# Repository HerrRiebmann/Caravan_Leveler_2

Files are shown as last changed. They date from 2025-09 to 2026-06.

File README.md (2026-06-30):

# Caravan Leveler 2.0
ESP32 digital water level bubble with an MPU6050 Gyroscope & Accelerometer

The successor of the [Caravan Leveler 1.0](https://github.com/HerrRiebmann/Caravan_Leveler)

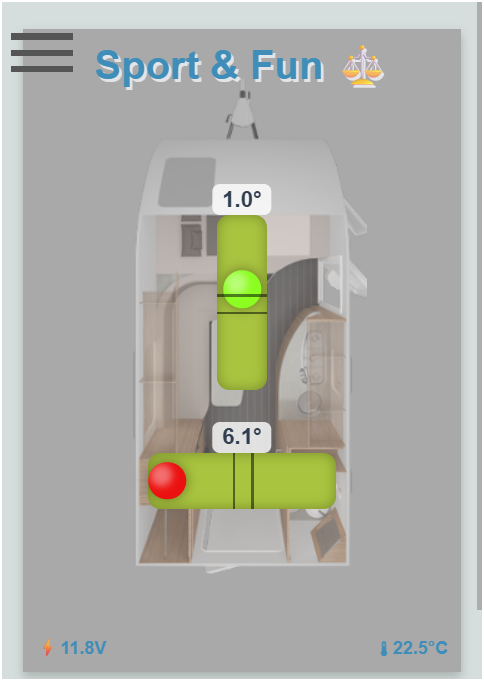
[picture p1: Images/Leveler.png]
Caravan Leveler


An ESP32 will create a hotspot with a captive portal.
This captive portal will force the phone to open up a, usually for login intended, website (_which represents the water level_).





## Contents
* [Usage](#usage)
* [Things](#Things)
* [Installation](#Installation)
* [HardwareComponents](#HardwareComponents)
  * [Wiring](#Wiring)
  * [SPIFFS Upload](#SPIFFS-Upload)
  * [Libraries](#Libraries)
  * [OTA (Over the Air Update)](#OTA-Over-the-Air-Update)
* [Compatibility](#Compatibility)
* [Demo](#Demo)
* [Video](#Video)

### Intention
The intention was, to attach this to my caravan (_Knaus Sport & Fun_) and provide it with 12V on-board voltage.
When arriving at a campingside, the phone will automatically connect to this as a known hotspot, open up the digital leveler and I can happily crank the supports.

In short: Lazy me doesn´t want to constantly walk to the inside and check the level &#129335;

## Usage

### Main Menu

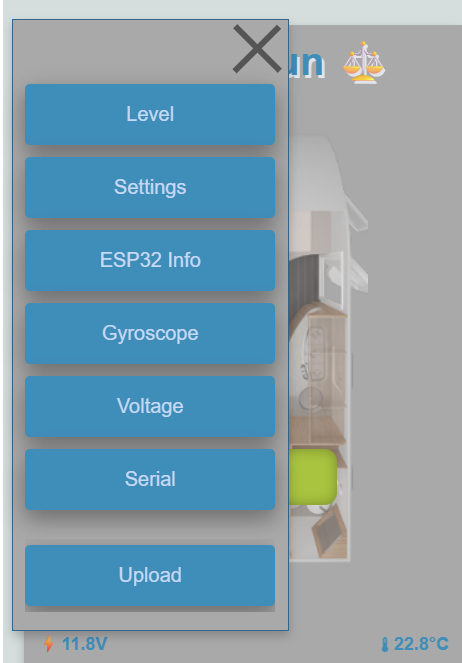
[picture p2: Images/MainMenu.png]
Main Menu


 * **Upload** loads a file to the SPIFFS filesystem. To overwrite existing files, the filename must be equal (see [/data](https://github.com/HerrRiebmann/Caravan_Leveler_2/tree/main/Caravan_Leveler_2/data))! The filenames are case sensitive!

  * Or updates the firmware by uploading a *.bin file.
  * Or updates the spiffs with a spiffs.*.bin file. See [Manual SPIFFS Upload](#Manual-SPIFFS-Upload)

### Settings

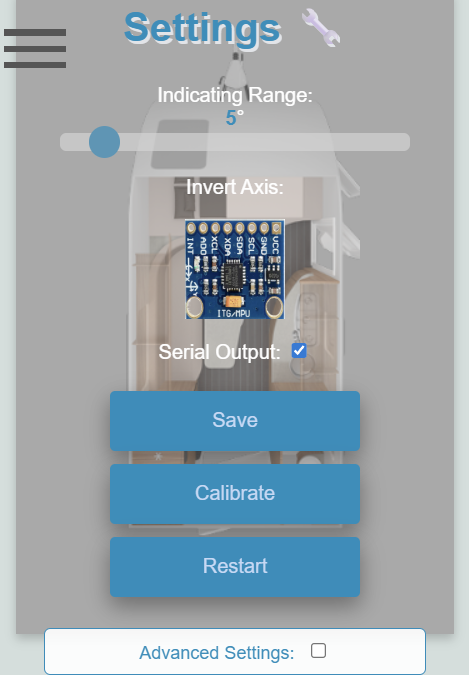
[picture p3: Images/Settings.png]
Settings


 * **Indicating Range** describes the water bubble maximum value, when it will reach the scales end

 * **Invert Axis** turns the MPU6050 Gyro (_swaps X- and Y-Axis_)

 * **Serial Output** enables USB serial (_and webbased_) output 

 * **Save** will store all values to the ESP32

 * **Calibrate** sets the current degrees to zero (ensure the Gyro is leveled)

 * **Restart** reboots the ESP32

 * **Advanced Settings** opens further settings

Advanced Settings:

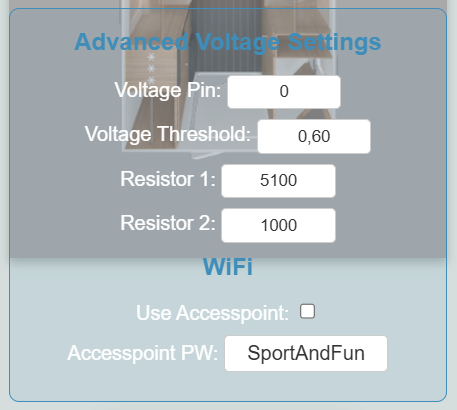
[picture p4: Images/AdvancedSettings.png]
Advanced Settings

#### Advanced Voltage Settings

 * **Voltage Pin** Analog ADC pin number for voltage measurement (0-36) *Check your ESP for ADC inputs!*

 * **Voltage Threshold** threshold to correct differences by diodes and resistors

 * **Resistor 1** First resistor value in ohms for voltage divider (After 12V, Before measuring)

 * **Resistor 2** Second resistor value in ohms for voltage divider (After measuring, before GND)

#### WiFi

 * **Use Accesspoint** or connect to an existing WiFi (_SSID and Pasword required in code or can be set on the web-installer_)

 * **Accesspoint PW** Password to secure the Accesspoint access

#### MPU6050

 * **SDA Pin** I²C Serial Data GPIO

 * **SCL Pin** I²C Serial Clock Line GPIO
   
 * **I²C Adress** Integer representation for the I2C adress (104 or 105)

### Gimmicks

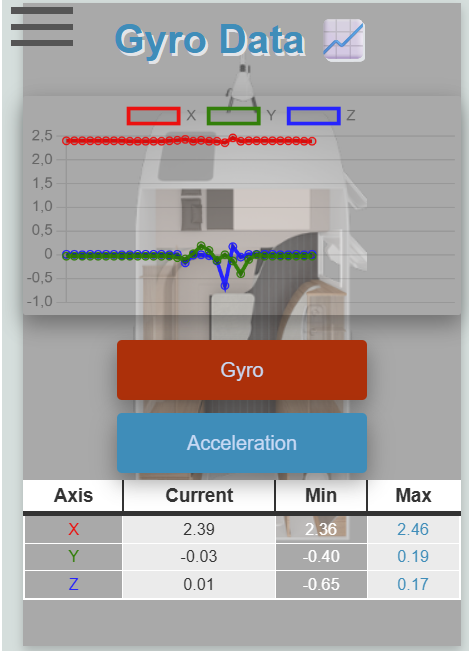
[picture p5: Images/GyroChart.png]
Gyro Chart


A Chart for Gyro, Acceleration and Voltage. Mostly just to debug and play around.

The Serial is also only implemented for testing purpose.

## Things
### Installation
You can download the files here, add the additional libraries and flash them via the Arduino IDE. All Libraries & Tools mentioned below.
Or you can use the ESP32 Web firmware flash-method, which will install all the required components directly onto the ESP.

Currently supported Versions are ESP32, ESP32-S3 & ESP32-C3.

[Caravan Leveler - Web Installer](https://trib.free.nf/flash.html?source=github)

This makes use of the [ESP Web Tools](https://esphome.github.io/esp-web-tools/) from ESPhome, hosted on unpkg.com.

### HardwareComponents
* ESP32 C3 Supermini (Any other ESP32 will work)
* MPU6050 (_Accelerometer / Gyro_)
* LM2596 (_DC-DC converter_)
* 5.2k & 1k Ohm Resistor (_For measuring voltage_)
* 2 Diodes to prevent voltage reversing (_like SR560 or SB5100_)

### Wiring
Wiring for my tested ESP32 types. Check the I2C pinout for your board!

 MPU6050 | ESP 32 | ESP32-S3 | ESP32-C3
 -------- |-------|-------|-------
 SCL | G22 | G09 | G09
 SDA | G21 | G08 | G08
 VCC | 3.3V | 3.3V | 3.3V
 GND | GND | GND | GND

The I²C adress will be 0x68 (Integer 104). In some cases, this might be 0x69 (105) when the jumper is set onto the board.

ESP 32 | LM2596
------- | --------
VIN 5V | OUT+
GND | OUT-

**Voltage Divider**
Any possible ADC Pin can be used. Please check it with the pinout for your device from the ESP32-family.

 Type | Pin
  ----- | -----
  ESP32 | 34
  ESP32-S3 | 1
  ESP32-C3 | 0

For most other ESP32 Development Boards pin 30-36.

```
-Supply voltage (max 15V!!!)
|----LM2596 IN+
|5.2k Resistor
|----Connect ADC-Pin
|1k Resistor
|----LM2596 IN-
-GND
```

### Schematic
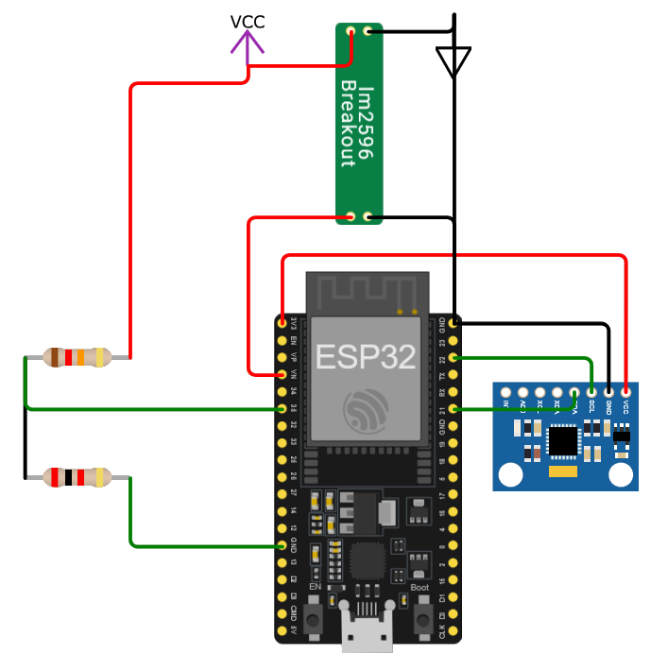
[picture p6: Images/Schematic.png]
Schematic


Diodes to secure the parts from reversed polarity were highly recommended!

### SPIFFS Upload
To upload the HTML, JS and CSS files, I´ve used the [Arduino ESP32 filesystem uploader](https://github.com/me-no-dev/arduino-esp32fs-plugin)
You can find the latest release [here](https://github.com/me-no-dev/arduino-esp32fs-plugin/releases/) and a tutorial on [RandomNerdTutorials](https://randomnerdtutorials.com/install-esp32-filesystem-uploader-arduino-ide/)

For **Arduino IDE 2.X** use the VSIX from [arduino-spiffs-upload](https://github.com/espx-cz/arduino-spiffs-upload) 

_This is only necessary if you want to compile the code yourself and upload the webinterface to the ESP32 afterwards._

#### Manual SPIFFS Upload
It is possible to use the Upload functionality on the Caravan Leveler to update the Website files all at once.
It automatically indentifies if this is a SPIFFS package an put it on the right spot on the storage.

The SPIFFS binary can be found here: [spiffs-binary](https://trib.free.nf/spiffs.bin) 

_Be aware, all your image customizations will be overwritten. The Settings will not be affected_

### Libraries
* Adafruit_MPU6050.h ([2.2.6](https://github.com/adafruit/Adafruit_MPU6050))
* Adafruit Unified Sensor ([1.1.15](https://github.com/adafruit/Adafruit_Sensor))
* Improv WiFi Library ([0.0.1](https://github.com/jnthas/Improv-WiFi-Library))

### OTA (Over the Air Update)
You should see the ESP32 in Arduino IDE under Tools -> Port -> Network-Interfaces (Caravan Leveler at _IP-Adress_)
For more information see [RandomNerdTutorials](https://randomnerdtutorials.com/esp32-over-the-air-ota-programming/)

## Compatibility
Installed on ESP32 C3 Supermini, ESP-WROOM-32 DevBoard and ESP32-S3-WROOM-1 DevBoard (with 2 USB-C)
Tested on Firefox, Chrome & Edge for Windows, iOS and Chrome & Firefox for Android.

## Demo
The website, which will be hosted on the ESP32 can be tested here:
[Caravan Leveler 2.0 - Demo](https://trib.free.nf/CaravanLevelerDemo/index.html?source=github)

## Video
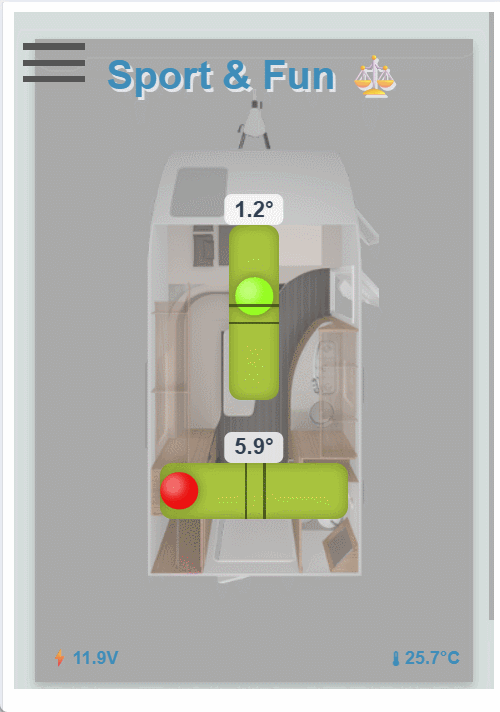
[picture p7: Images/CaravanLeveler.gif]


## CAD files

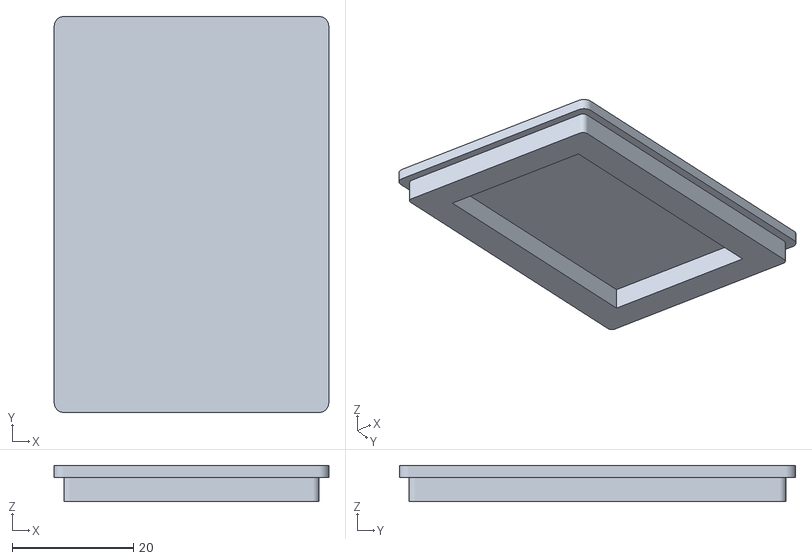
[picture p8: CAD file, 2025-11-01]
3D Case/ESP32 Supermini on Board/Caravan Leveler 2-Lid V3.stl
45.2 x 65.2 x 6.00

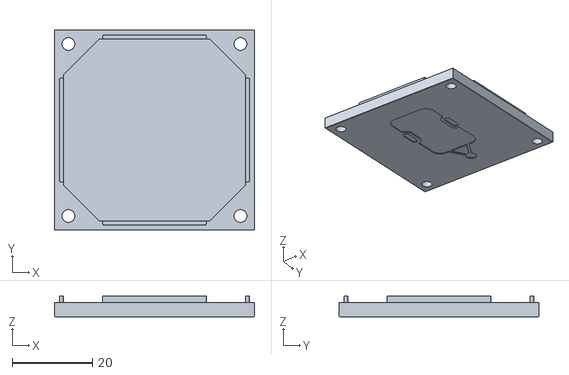
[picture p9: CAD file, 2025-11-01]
3D Case/ESP32/DeckelLeveler.stl
50.0 x 50.0 x 5.20

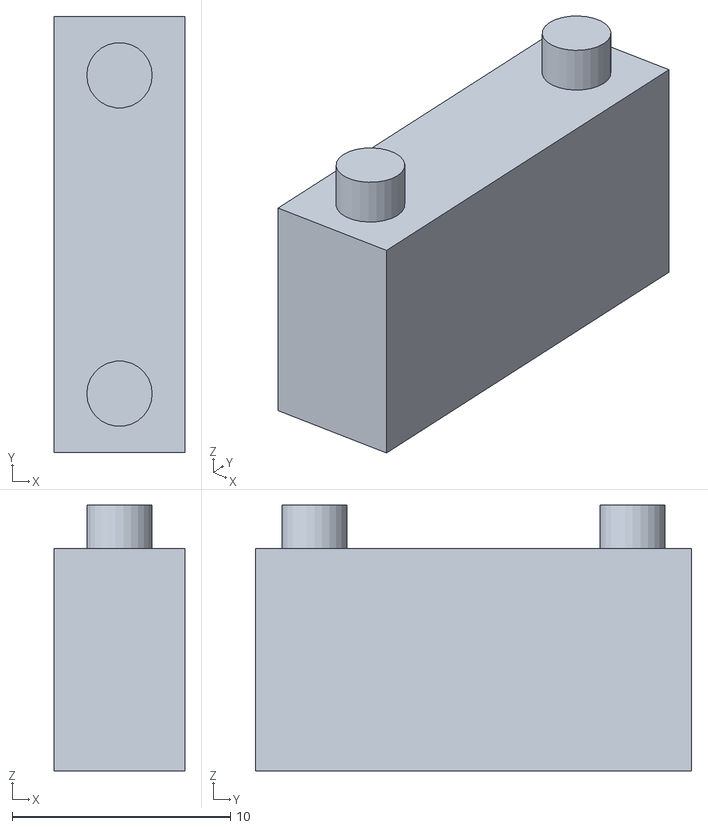
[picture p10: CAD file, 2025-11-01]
3D Case/ESP32 Supermini on Board/Caravan Leveler 2-GyroHolder.stl
6.00 x 20.0 x 12.2

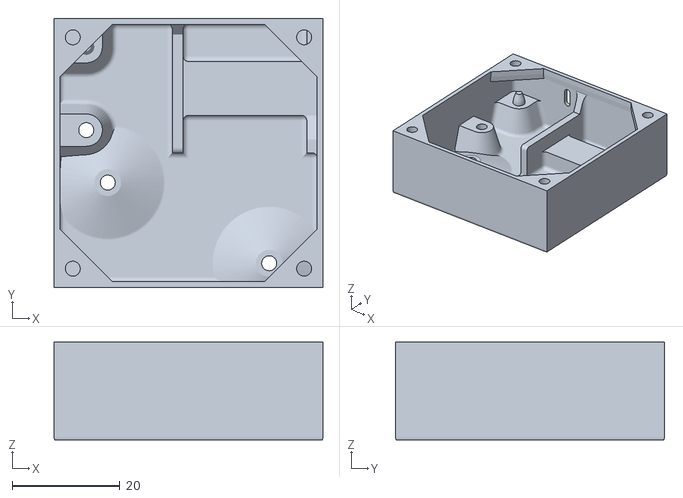
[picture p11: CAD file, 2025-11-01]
3D Case/ESP32/GehauseLeveler.stl
50.0 x 50.0 x 18.2

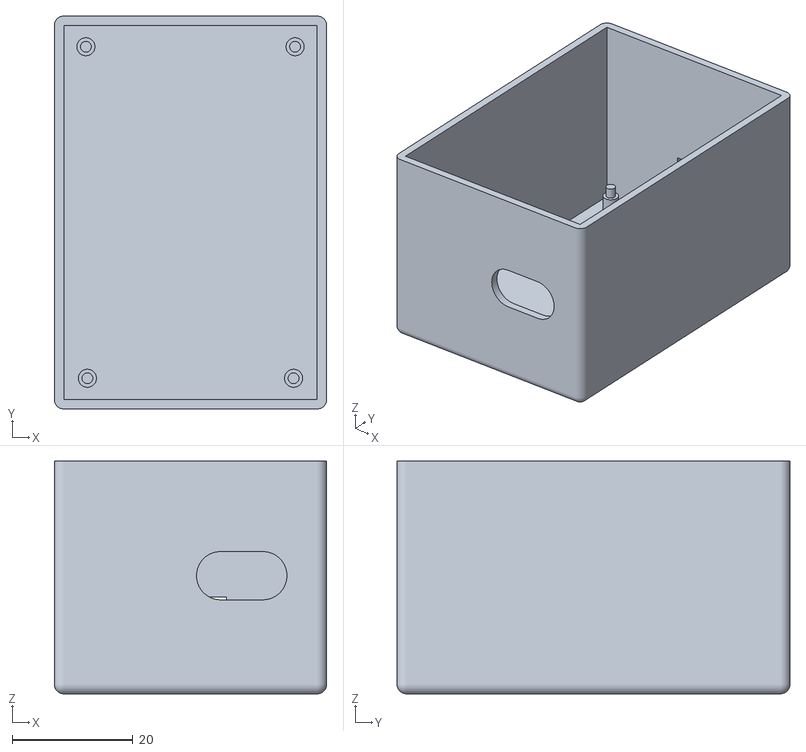
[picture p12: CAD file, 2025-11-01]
3D Case/ESP32 Supermini on Board/Caravan Leveler 2-Body V2.stl
45.2 x 65.2 x 38.6

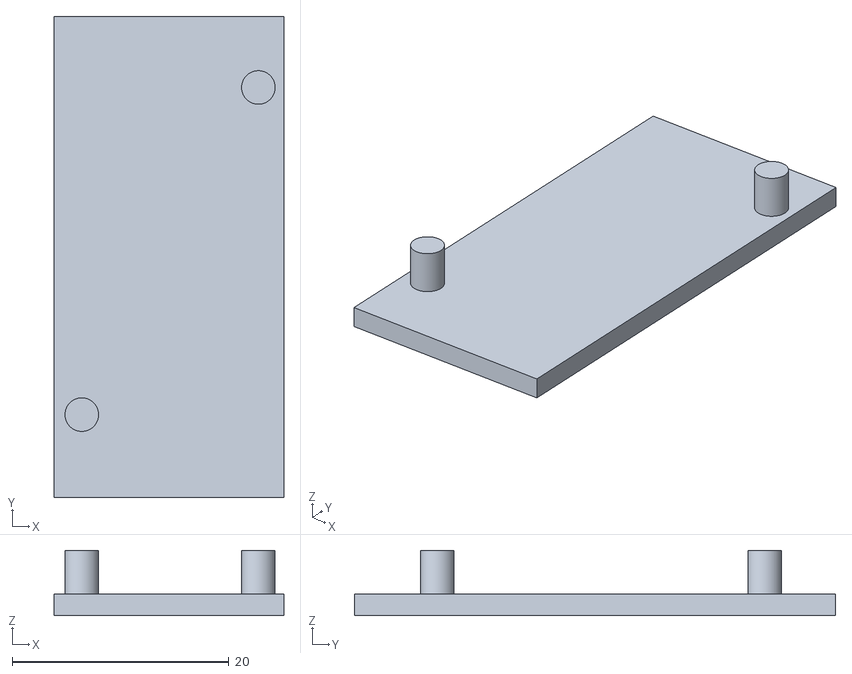
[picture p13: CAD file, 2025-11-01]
3D Case/ESP32 Supermini on Board/Caravan Leveler 2-Separator V2.stl
21.2 x 44.4 x 6.00

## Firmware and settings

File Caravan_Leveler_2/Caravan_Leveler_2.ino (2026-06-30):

#define DEBUG false //Uses my personal WiFi Credentials

//Fri3d Badge 2024 (ESP32-S3-WROOM1)
//Nologo ESP32C3 Super Mini
//ESP32 Dev Module

//Gyro MPU6050 (custom implementation - accepts compatible device IDs)
#include <Adafruit_Sensor.h>
#include <Wire.h>
#include "MPU6050.h"
Custom_MPU6050 mpu;

//Over the Air Update
#include <ArduinoOTA.h>

//Filesystem
#define USE_LITTLE_FS false

#if USE_LITTLE_FS
  #include "LittleFS.h"
  #define SPIFFS LittleFS
  const int FS_PartitionStart = U_LITTLEFS;  
#else
  #include "SPIFFS.h"
  const int FS_PartitionStart = U_SPIFFS;
#endif

//Webserver
#include <WiFi.h>
#include <WebServer.h>

//Setup WiFi from SerialPort
#include <ImprovWiFiLibrary.h>

#include <Preferences.h>

#if DEBUG
#include <Credentials.h>
String ssid = WIFI_SSID;
String password = WIFI_PASSWORD;
#else
String ssid = "";
String password = "";
#endif

WebServer webServer(80);
ImprovWiFi improvSerial(&Serial);

#include <DNSServer.h>
const byte DNS_PORT = 53;
DNSServer dnsServer;

const char deviceName[] = "Caravan Leveler";
String devicePassword = "SportAndFun";

bool accelInitialized = false;
float calibrationX = -0.0;
float calibrationY = -0.0;

float pitch, roll, temperature, voltage;

long lastMillisClientAvailable = 0;
bool voltage_read = false;
String logBuffer;

bool UploadIsOTA = false;
bool UploadIsSPIFFS = false;

//Settings
Preferences settings;
bool Serial_Enabled = true;
bool OTA_Enabled = true;
uint8_t levelThreshold = 5;
int invertAxis = 0;
bool useAcessPointMode = false;
bool dampingEnabled = false;
float voltThreshold = 0.0;
int resistor1 = 5100;
int resistor2 = 1000;
#if CONFIG_IDF_TARGET_ESP32
uint8_t voltagePin = 34;
#elif CONFIG_IDF_TARGET_ESP32C3
uint8_t voltagePin = 0;
#elif CONFIG_IDF_TARGET_ESP32S3
uint8_t voltagePin = 2;
#else
#error Target CONFIG_IDF_TARGET is not supported
#endif
uint8_t MPU_SDA = SDA;
uint8_t MPU_SCL = SCL;
uint8_t MPU_Adress = MPU6050_I2CADDR_DEFAULT;//0x68;

void logPrintLn(const String &msg);
void logPrint(const String &msg, bool linebreak = false);

void setup() {
  SerialBegin();

  setupImprov();

  SpiffsBegin();  

  LoadData();

  MPU6050Begin();

  WiFiBegin();

  setupOTA();

  InitializeVoltageMeasuring();
}

void loop() {
  //WebServer
  webServer.handleClient();

  //DNS
  dnsServer.processNextRequest();

  //OTA
  OTA_Handle();

  //Improv Setup Wifi by serial:
  loopImprov();
}

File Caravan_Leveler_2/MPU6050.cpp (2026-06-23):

// Custom MPU6050 implementation that accepts any compatible device ID
// (MPU6050, MPU6500, MPU9250, clones, etc.)


/*!
 *  @file Custom_MPU6050.cpp
 *
 *  @mainpage Adafruit MPU6050 6-DoF Accelerometer and Gyro Library
 *
 *  @section intro_sec Introduction
 *
 * 	I2C Driver for the MPU6050 6-DoF accelerometer and gyro sensor library
 *
 * 	This is a library for the Adafruit MPU6050 breakout:
 * 	https://www.adafruit.com/product/3886
 *
 * 	Adafruit invests time and resources providing this open source code,
 *  please support Adafruit and open-source hardware by purchasing products from
 * 	Adafruit!
 *
 *  @section dependencies Dependencies
 *
 *  This library depends on the Adafruit BusIO library
 *
 *  @section author Author
 *
 *  Bryan Siepert for Adafruit Industries
 *
 * 	@section license License
 *
 * 	BSD (see license.txt)
 *
 * 	@section  HISTORY
 *
 *     v1.0 - First release
 */

#include "Arduino.h"
#include <Wire.h>

#include <MPU6050.h>

/*!
 *    @brief  Instantiates a new MPU6050 class
 */
Custom_MPU6050::Custom_MPU6050(void) {}

/*!
 *    @brief  Cleans up the MPU6050 class
 */
Custom_MPU6050::~Custom_MPU6050(void) {
  if (temp_sensor)
    delete temp_sensor;
  if (accel_sensor)
    delete accel_sensor;
  if (gyro_sensor)
    delete gyro_sensor;
  if (i2c_dev)
    delete i2c_dev;
}

/*!
 *    @brief  Sets up the hardware and initializes I2C
 *    @param  i2c_address
 *            The I2C address to be used.
 *    @param  wire
 *            The Wire object to be used for I2C connections.
 *    @param sensor_id
 *            The user-defined ID to differentiate different sensors
 *    @return True if initialization was successful, otherwise false.
 */

bool Custom_MPU6050::begin(uint8_t i2c_address, TwoWire *wire,
                             int32_t sensor_id) {
  if (i2c_dev) {
    delete i2c_dev; // remove old interface
  }

  i2c_dev = new Adafruit_I2CDevice(i2c_address, wire);

  // For boards with I2C bus power control, may need to delay to allow
  // MPU6050 to come up after initial power.
  bool mpu_found = false;
  for (uint8_t tries = 0; tries < 5; tries++) {
    mpu_found = i2c_dev->begin();
    if (mpu_found)
      break;
    delay(10);
  }
  if (!mpu_found)
    return false;

  Adafruit_BusIO_Register chip_id =
      Adafruit_BusIO_Register(i2c_dev, MPU6050_WHO_AM_I, 1);

  // make sure we're talking to the right chip
  // if (chip_id.read() != MPU6050_DEVICE_ID) {
  //   return false;
  // }

  // Read WHO_AM_I register
  uint8_t deviceId = chip_id.read();  
  //Allow more vendor device ID´s
  if (deviceId == 0x00 || deviceId == 0xFF)
    // No valid response - sensor not connected properly
    return false;

  return _init(sensor_id);
}

/*!  @brief Initilizes the sensor
 *   @param sensor_id Optional unique ID for the sensor set
 *   @returns True if chip identified and initialized
 */
bool Custom_MPU6050::_init(int32_t sensor_id) {

  _sensorid_accel = sensor_id;
  _sensorid_gyro = sensor_id + 1;
  _sensorid_temp = sensor_id + 2;

  reset();

  setSampleRateDivisor(0);

  setFilterBandwidth(MPU6050_BAND_260_HZ);

  setGyroRange(MPU6050_RANGE_500_DEG);

  setAccelerometerRange(MPU6050_RANGE_2_G); // already the default

  Adafruit_BusIO_Register power_mgmt_1 =
      Adafruit_BusIO_Register(i2c_dev, MPU6050_PWR_MGMT_1, 1);

  power_mgmt_1.write(0x01); // set clock config to PLL with Gyro X reference

  delay(100);

  // remove old reference
  if (temp_sensor)
    delete temp_sensor;
  if (accel_sensor)
    delete accel_sensor;
  if (gyro_sensor)
    delete gyro_sensor;

  temp_sensor = new Custom_MPU6050_Temp(this);
  accel_sensor = new Custom_MPU6050_Accelerometer(this);
  gyro_sensor = new Custom_MPU6050_Gyro(this);

  return true;
}
/**************************************************************************/
/*!
    @brief Resets registers to their initial value and resets the sensors'
    analog and digital signal paths.
*/
/**************************************************************************/
void Custom_MPU6050::reset(void) {
  Adafruit_BusIO_Register power_mgmt_1 =
      Adafruit_BusIO_Register(i2c_dev, MPU6050_PWR_MGMT_1, 1);
  Adafruit_BusIO_Register sig_path_reset =
      Adafruit_BusIO_Register(i2c_dev, MPU6050_SIGNAL_PATH_RESET, 1);
  Adafruit_BusIO_RegisterBits device_reset =
      Adafruit_BusIO_RegisterBits(&power_mgmt_1, 1, 7);

  // see register map page 41
  device_reset.write(1);             // reset
  while (device_reset.read() == 1) { // check for the post reset value
    delay(1);
  }
  delay(100);

  sig_path_reset.write(0x7);

  delay(100);
}

/**************************************************************************/
/*!
    @brief Gets the sample rate divisor.
    @return  The sample rate divisor
*/
/**************************************************************************/
uint8_t Custom_MPU6050::getSampleRateDivisor(void) {
  Adafruit_BusIO_Register sample_rate_div =
      Adafruit_BusIO_Register(i2c_dev, MPU6050_SMPLRT_DIV, 1);
  return sample_rate_div.read();
}

/**************************************************************************/
/*!
    @brief  Sets the divisor used to divide the base clock rate into a
            measurement rate
    @param  divisor
            The new clock divisor
*/
/**************************************************************************/
void Custom_MPU6050::setSampleRateDivisor(uint8_t divisor) {
  Adafruit_BusIO_Register sample_rate_div =
      Adafruit_BusIO_Register(i2c_dev, MPU6050_SMPLRT_DIV, 1);
  sample_rate_div.write(divisor);
}

/**************************************************************************/
/*!
    @brief Gets the acceleration measurement range.
    @return  The acceleration measurement range
*/
/**************************************************************************/
mpu6050_accel_range_t Custom_MPU6050::getAccelerometerRange(void) {
  Adafruit_BusIO_Register accel_config =
      Adafruit_BusIO_Register(i2c_dev, MPU6050_ACCEL_CONFIG, 1);
  Adafruit_BusIO_RegisterBits accel_range =
      Adafruit_BusIO_RegisterBits(&accel_config, 2, 3);

  return (mpu6050_accel_range_t)accel_range.read();
}

/**************************************************************************/
/*!
    @brief Sets the accelerometer measurement range
    @param  new_range
            The new range to set. Must be a `mpu6050_accel_range_t`
*/
/**************************************************************************/
void Custom_MPU6050::setAccelerometerRange(mpu6050_accel_range_t new_range) {
  Adafruit_BusIO_Register accel_config =
      Adafruit_BusIO_Register(i2c_dev, MPU6050_ACCEL_CONFIG, 1);

  Adafruit_BusIO_RegisterBits accel_range =
      Adafruit_BusIO_RegisterBits(&accel_config, 2, 3);
  accel_range.write(new_range);
}
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

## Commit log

2025-10-01 Hide Voltage and Temp when NaN
    Ignore Voltage or Temperature, when not available.
2025-10-06 GPIO correction for S3
    Changed PIN to 1 to measure voltage.
    [Caravan_Leveler_2.ino]
2025-10-06 Gyro not found
    Optimized not found Gyro
2025-10-07 Optimized Web
    Enhanced stability between web and ESP
    [Voltage.ino, Webserver.ino]
2025-10-17 Mobile Gyro demo
    Enhanced the Demo-Mode to use the mobile device gyro, when no ESP32 available.
2025-11-01 Initial Upload
    [Caravan Leveler 2-Body V2.stl, Caravan Leveler 2-GyroHolder.stl, Caravan Leveler 2-Lid V3.stl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]
2026-01-02 I2C Setup
    Enable I2C scan and setup for MPU6050
2026-02-23 Bugfix data storage
    Save/Load Bugfix for AP-password
    Changed order loading and initializing the MPU6050
    Added possibility to change to LittleFs
    [Caravan_Leveler_2.ino, Data.ino, Helper.ino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]
2026-06-23 MPU Support
    Copied Adafruit Library to support MPU6050 devices with a different Device Id (WhoAmI)
2026-10-29 Web-setup & overhead gyro
    Improved Improv Setup Handling via ESP Web Installer
    Added "overhead" calculation for Gyro
